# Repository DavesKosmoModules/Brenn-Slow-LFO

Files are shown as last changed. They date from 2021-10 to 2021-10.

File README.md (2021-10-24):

# Brenn-Slow-LFO

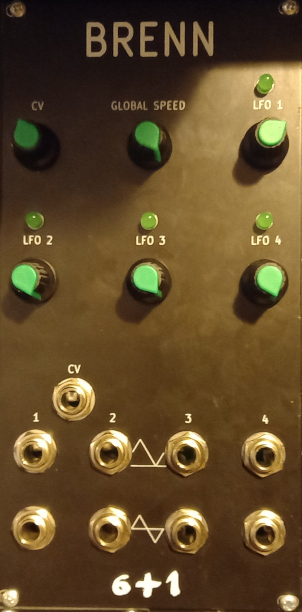
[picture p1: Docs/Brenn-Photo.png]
Brenn Photo


100mm Quad Slow LFO

- 4 Lfo's
- Each has a cycle duration between a few seconds and a few minutes, approx 6 sec 12 minutes
- Each LFO has it's own speed control
- A single global speed control
- CV control for the global speed (not 1V/Oct)
- Each LFO has both unipolar and bipolar outputs

I have been using the lfo for slow evolving movement of sounds, it is not a replacement for a standard lfo, normal tremolo
and vibrato can not be realized with this module.

It is based on the single cell VCO on the LM13700 datasheet, this is a triangle wave with a big step so I added
a LPF to each oscillator.

Contained are schematics & gerber files for pcb fabrication of both electrical aux and front panel. This is sutiable for entry level however a basic level of electronics, soldering, fault finding, and some basic tools are required.

[Schematic](/Docs/Brenn-Schematic.pdf)

[BOM](Docs/Brenn-BOM.pdf)

If you wish to edit in ki-cad the following dependencies are required

 https://github.com/holmesrichards/Kosmo_panel
 
 https://github.com/holmesrichards/aoKicad

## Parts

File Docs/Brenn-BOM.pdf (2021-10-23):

Id | Designator | Package | Quantity | Designation
| 1 RV3,RV4 | Potentiometer_Alpha_RD901F‐40‐00D_Single_Vertical_CircularHoles | | 2 100k

2

| C1,C2,C5,C6,C9,C10,C11,C12,C13,
| C14 | C_Disc_D6.0mm_W4.4mm_P5.00mm | | 10 0.1uF
| 3 C3,C4,C15,C16 | CP_Radial_D7.5mm_P2.50mm | | 4 470uF
| 4 C7,C8,C17,C18 | C_Disc_D6.0mm_W4.4mm_P5.00mm | | 4 1uF
| 5 C19,C20 | CP_Radial_D7.5mm_P2.50mm | | 2 10uF
| 6 D1,D2,D3,D4,D6,D7,D8,D9 | D_DO‐35_SOD27_P7.62mm_Horizontal | | 8 1N914
| 7 D5,D10,D11,D14 | LED_D5.0mm | | 4 LED
| 8 D12,D13 | D_DO‐41_SOD81_P12.70mm_Horizontal | | 2 1N5817
| 9 J1 | IDC‐Header_2x05_P2.54mm_Vertical | | 1 Power
| 10 J2 | PinSocket_1x12_P2.54mm_Vertical | | 1 TO JACKS
| 11 Q1,Q2,Q3,Q4 | TO‐92_Inline_Wide | | 4 2N3904

12

R1,R6,R7,R8,R14,R15,R16,R17,R18
,R19,R20,R21,R22,R27,R33,R34,R3
5,R39,R43,R44,R45,R46,R47,R48,R
49 | R_Axial_DIN0207_L6.3mm_D2.5mm_P10.16mm_Horizontal | 25 100k
13 R2,R3,R4,R5,R29,R30,R31,R32 | R_Axial_DIN0207_L6.3mm_D2.5mm_P10.16mm_Horizontal | 8 7.5k
14 R9,R10,R37,R38 | R_Axial_DIN0207_L6.3mm_D2.5mm_P10.16mm_Horizontal | 4 5.1k
15 R12,R13,R40,R41 | R_Axial_DIN0207_L6.3mm_D2.5mm_P10.16mm_Horizontal | 4 1M

16

R23,R24,R25,R26,R51,R52,R53,R5
4 | R_Axial_DIN0207_L6.3mm_D2.5mm_P10.16mm_Horizontal | 8 1k
17 R28,R36,R42,R50 | R_Axial_DIN0207_L6.3mm_D2.5mm_P10.16mm_Horizontal | 4 10k
18 RV1,RV2,RV6,RV7 | Potentiometer_Alpha_RD901F‐40‐00D_Single_Vertical_CircularHoles | 4 1M
19 RV8 | Potentiometer_Bourns_3299W_Vertical | 1 100k
20 U1,U2 | DIP‐16_W7.62mm_LongPads | 2 LM13700
21 U3,U4,U5 | DIP‐14_W7.62mm_LongPads | 3 TL074

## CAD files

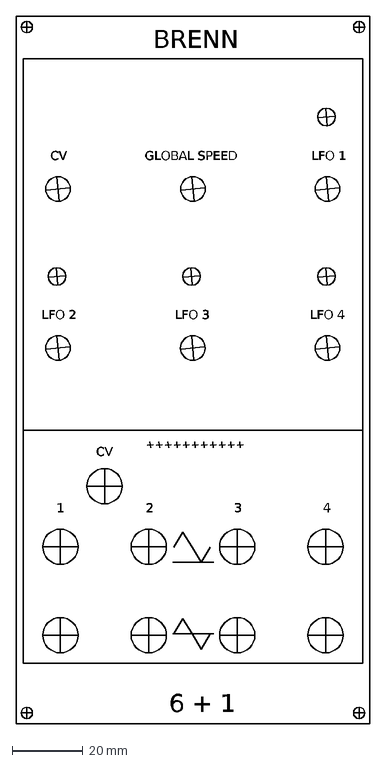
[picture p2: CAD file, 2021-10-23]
dwg/Frontv2.dxf
BRENN
CV
GLOBAL SPEED
LFO 1
LFO 2
LFO 3
LFO 4
1
2
3
4
6 + 1

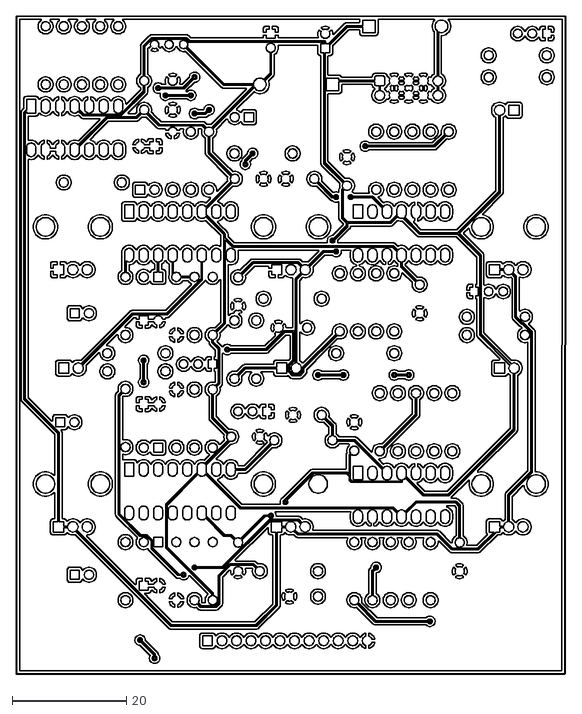
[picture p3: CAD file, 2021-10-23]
dwg/KOSMOS LFO6-F_Cu.dxf
96.1 x 115.1

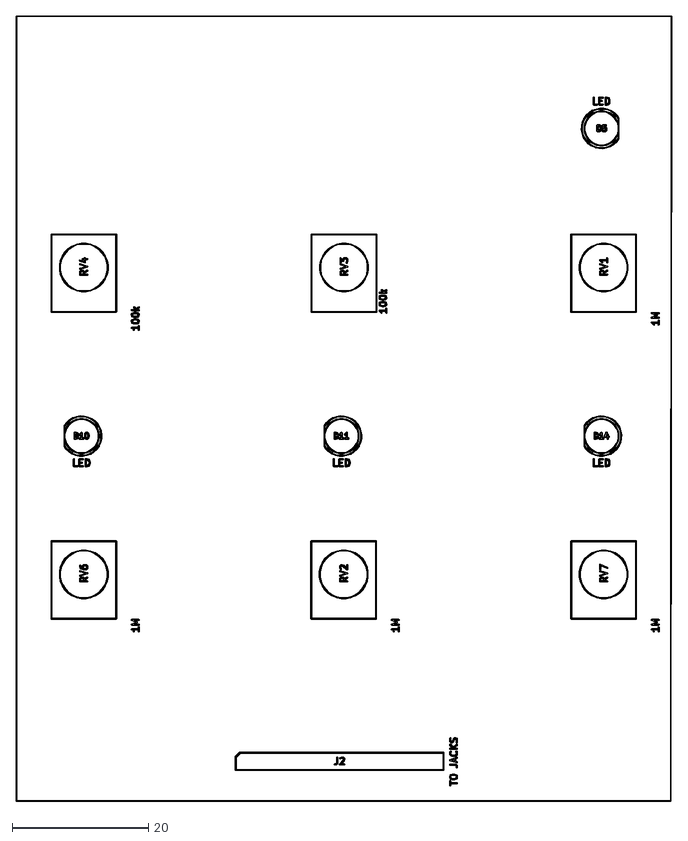
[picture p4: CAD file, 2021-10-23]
dwg/KOSMOS LFO6-F_Fab.dxf
96.1 x 115.1

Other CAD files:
dwg/KOSMOS LFO6-F_SilkS.dwg
dwg/LFOFrontPanel.dxf
dwg/KOSMOS LFO6-F_Cu.dwg
dwg/KOSMOS LFO6-F_Fab.dwg
dwg/KOSMOS LFO6-F_SilkS.dxf
dwg/LFOFrontPanel.dwg

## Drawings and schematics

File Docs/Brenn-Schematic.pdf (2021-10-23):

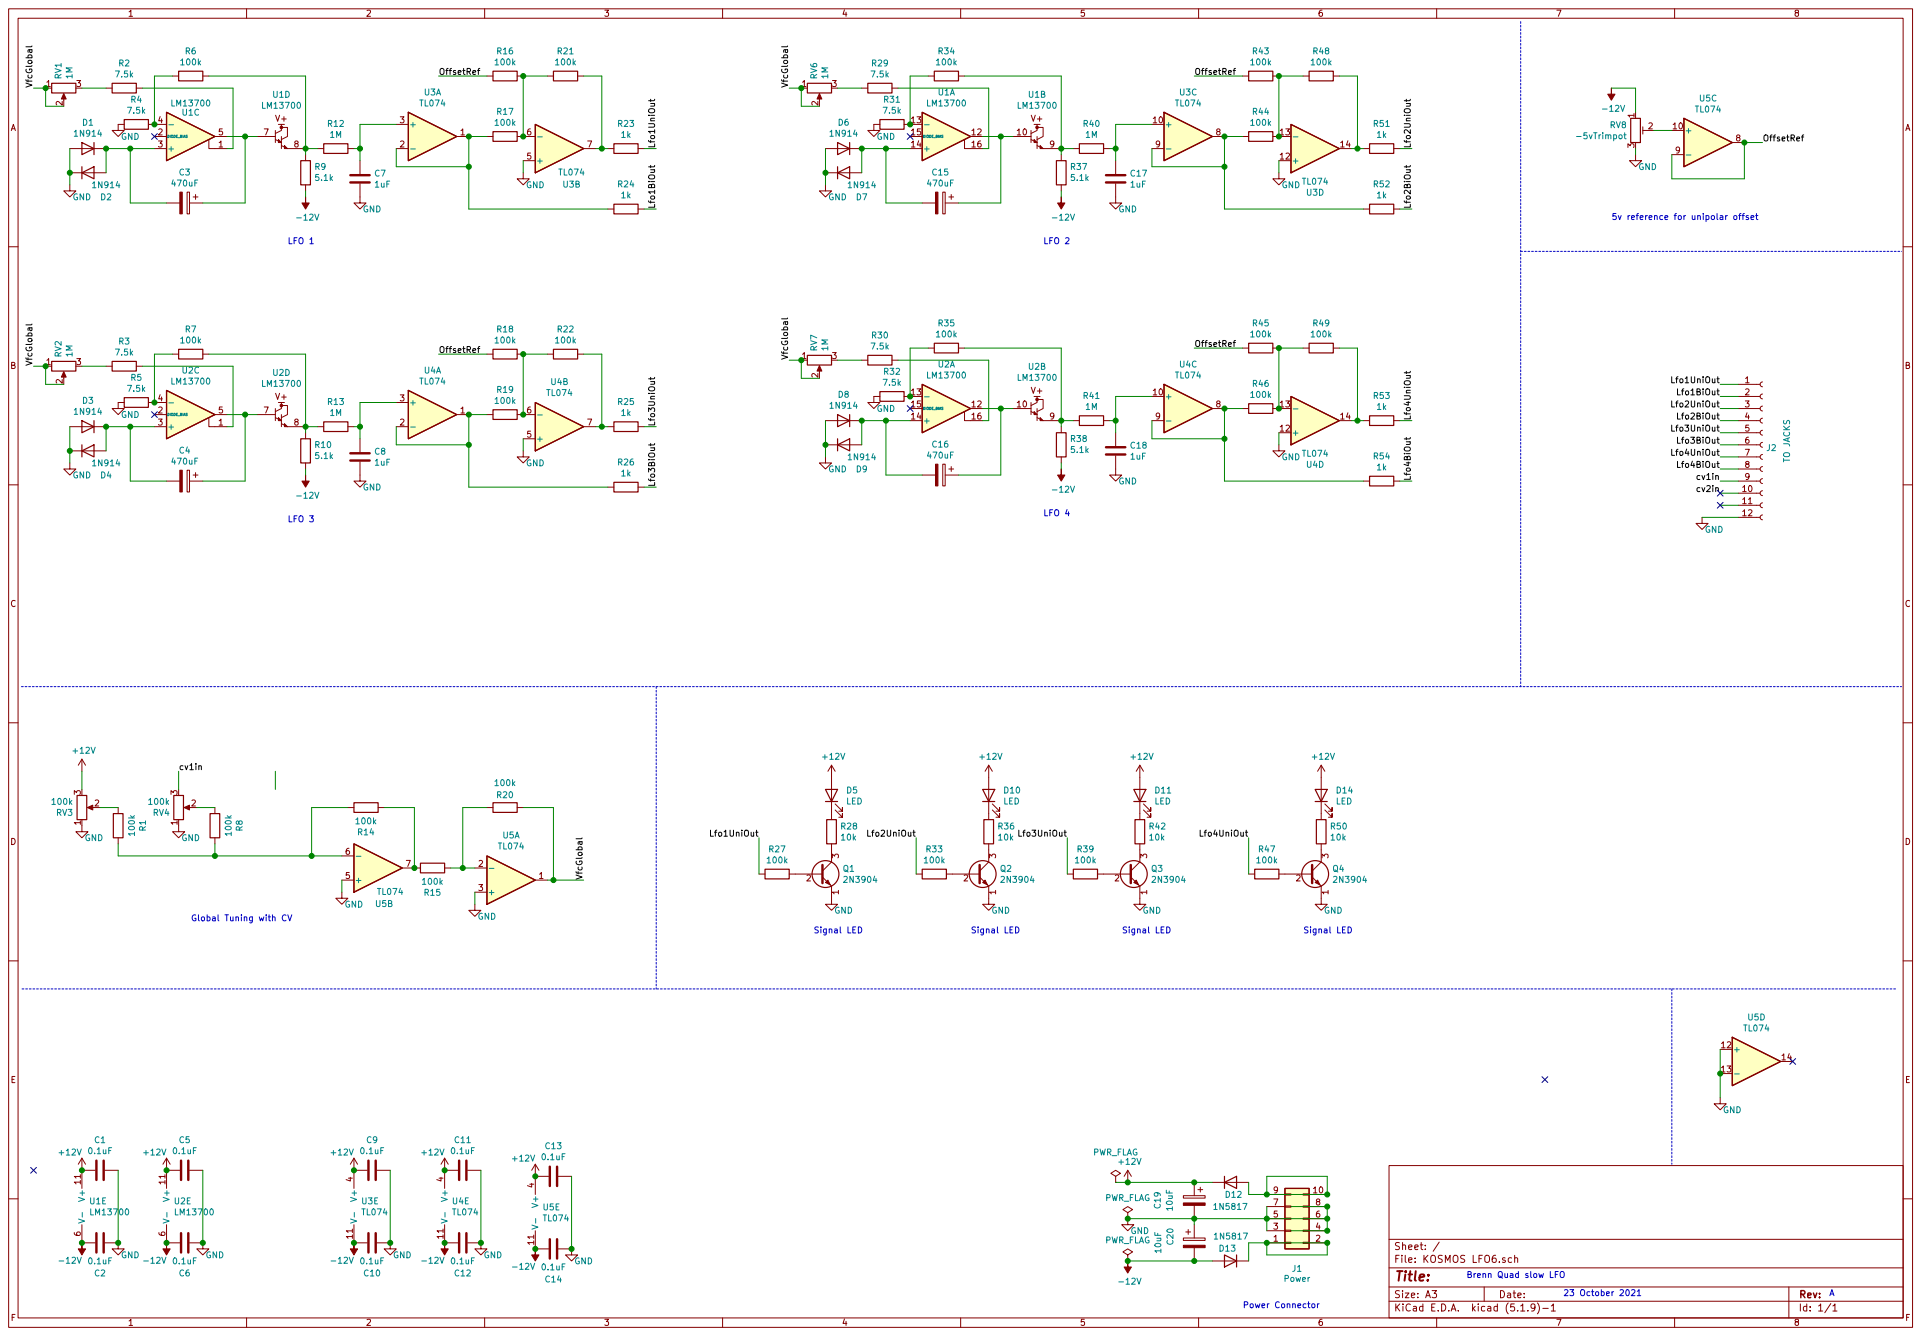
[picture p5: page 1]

5v reference for unipolar offset LFO 4

Global Tuning with CV

Brenn Quad slow LFO

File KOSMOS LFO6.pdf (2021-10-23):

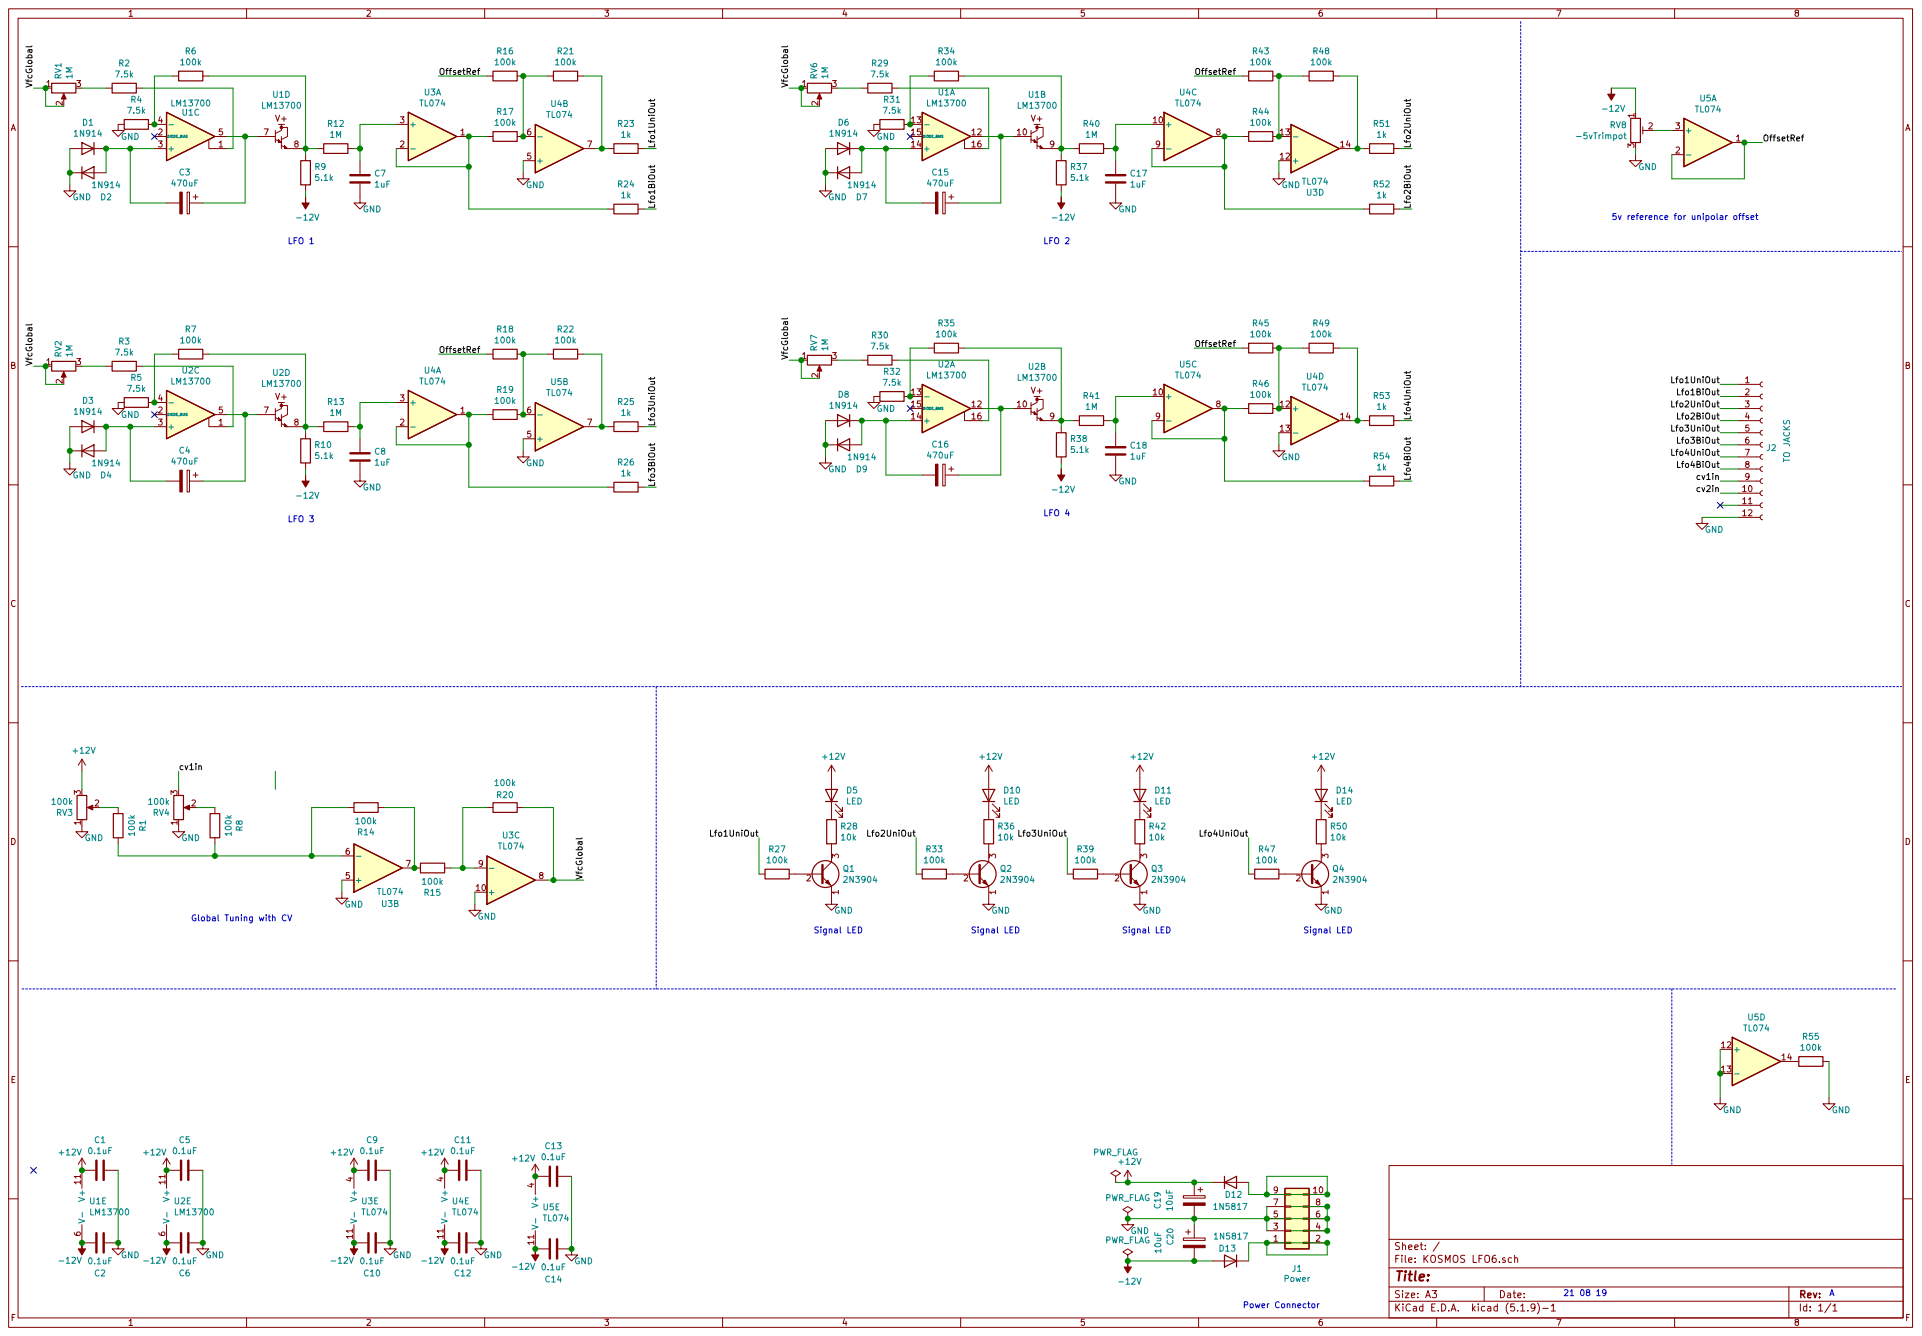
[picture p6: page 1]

5v reference for unipolar offset

Global Tuning with CV

Id: 1/1 Title: File: KOSMOS LFO6.sch Sheet: /

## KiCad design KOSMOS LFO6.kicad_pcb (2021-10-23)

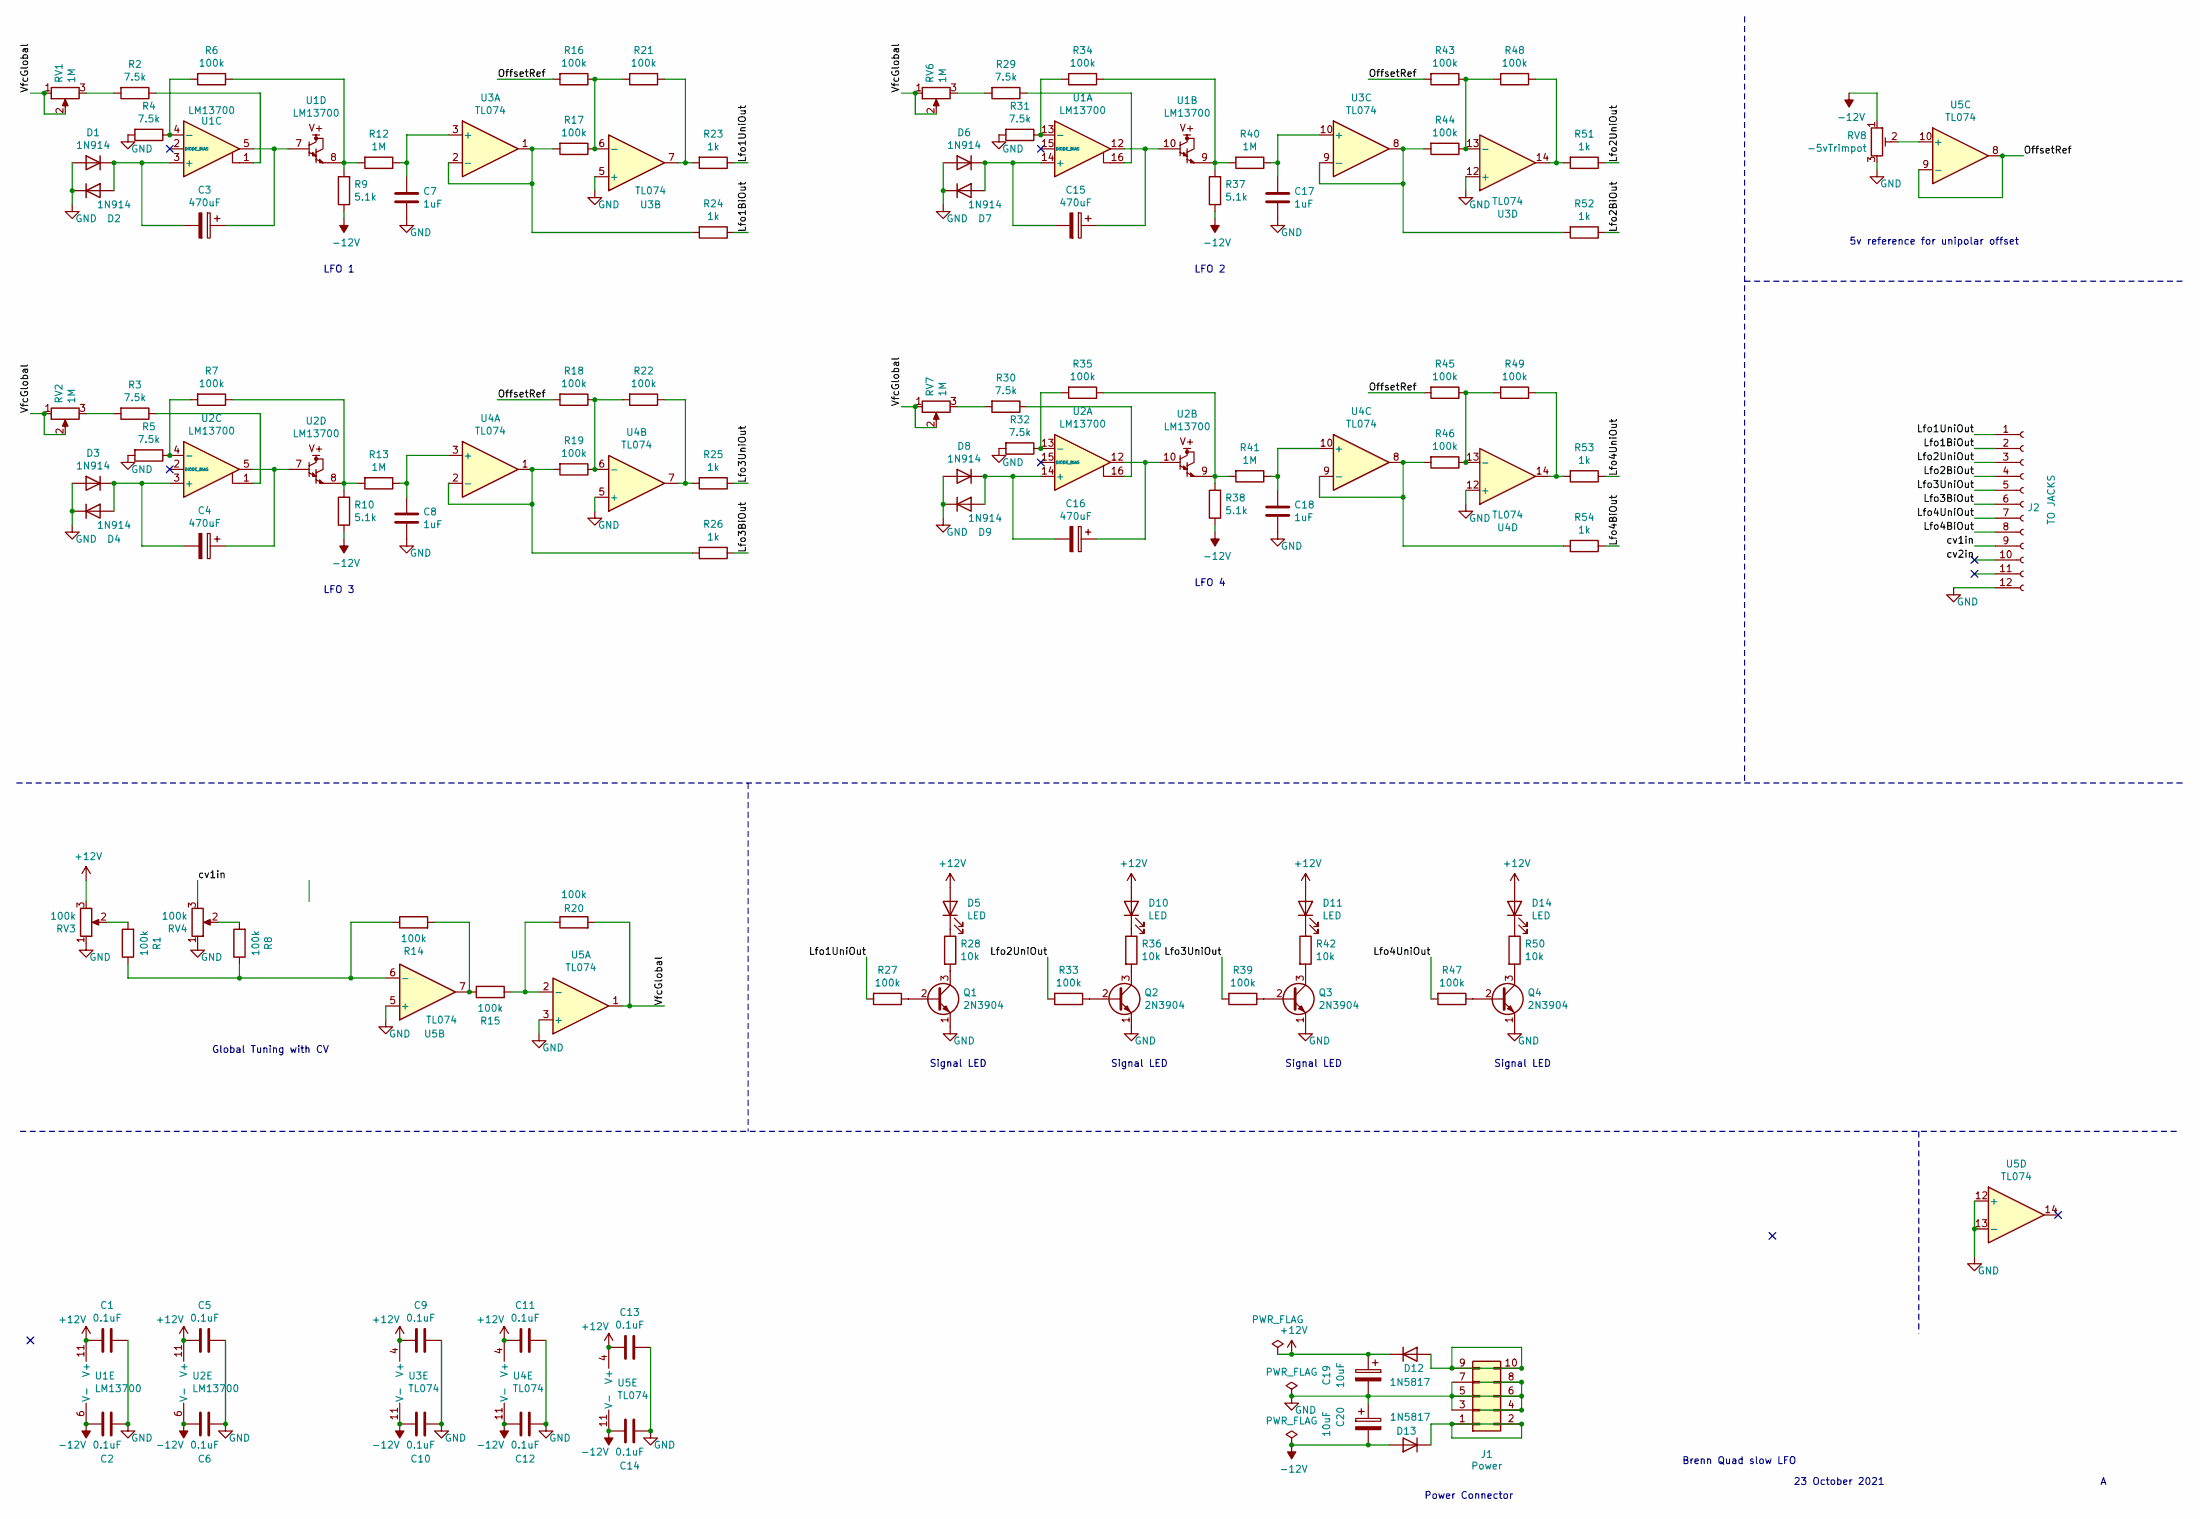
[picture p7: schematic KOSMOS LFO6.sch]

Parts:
C1, C2, C5, C6, C9, C10, C11, C12, C13, C14: 0.1uF; C_Disc_D6.0mm_W4.4mm_P5.00mm
C3, C4, C15, C16: 470uF; CP_Radial_D7.5mm_P2.50mm
C7, C8, C17, C18: 1uF; C_Disc_D6.0mm_W4.4mm_P5.00mm
C19, C20: 10uF; CP_Radial_D7.5mm_P2.50mm
D1, D2, D3, D4, D6, D7, D8, D9: 1N914; D_DO-35_SOD27_P7.62mm_Horizontal
D5, D10, D11, D14: LED; LED_D5.0mm
D12, D13: 1N5817; D_DO-41_SOD81_P12.70mm_Horizontal
J1: Power; IDC-Header_2x05_P2.54mm_Vertical
J2: TO JACKS; PinSocket_1x12_P2.54mm_Vertical
Q1, Q2, Q3, Q4: 2N3904; TO-92_Inline_Wide
R1, R6, R7, R8, R14, R15, R16, R17, R18, R19, R20, R21, R22, R27, R33, R34, R35, R39, R43, R44, R45, R46, R47, R48, R49: 100k; R_Axial_DIN0207_L6.3mm_D2.5mm_P10.16mm_Horizontal
R2, R3, R4, R5, R29, R30, R31, R32: 7.5k; R_Axial_DIN0207_L6.3mm_D2.5mm_P10.16mm_Horizontal
R9, R10, R37, R38: 5.1k; R_Axial_DIN0207_L6.3mm_D2.5mm_P10.16mm_Horizontal
R12, R13, R40, R41: 1M; R_Axial_DIN0207_L6.3mm_D2.5mm_P10.16mm_Horizontal
R23, R24, R25, R26, R51, R52, R53, R54: 1k; R_Axial_DIN0207_L6.3mm_D2.5mm_P10.16mm_Horizontal
R28, R36, R42, R50: 10k; R_Axial_DIN0207_L6.3mm_D2.5mm_P10.16mm_Horizontal
RV1, RV2, RV6, RV7: 1M; Potentiometer_Alpha_RD901F-40-00D_Single_Vertical_CircularH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
RV3, RV4: 100k; Potentiometer_Alpha_RD901F-40-00D_Single_Vertical_CircularH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
RV8: -5vTrimpot; Potentiometer_Bourns_3299W_Vertical
U1, U2: LM13700; DIP-16_W7.62mm_LongPads
U3, U4, U5: TL074; DIP-14_W7.62mm_LongPads

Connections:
+12V: C1.2, C5.2, C9.2, C11.2, C13.2, C19.1, D5.2 (A), D10.2 (A), D11.2 (A), D12.1 (K), D14.2 (A), RV3.3, U1.11 (V+), U2.11 (V+), U3.4 (V+), U4.4 (V+), U5.4 (V+)
-12V: C2.2, C6.2, C10.2, C12.2, C14.2, C20.2, D13.2 (A), R9.1, R10.1, R37.1, R38.1, RV8.1, U1.6 (V-), U2.6 (V-), U3.11 (V-), U4.11 (V-), U5.11 (V-)
/Lfo1BiOut: J2.2, R24.1
/Lfo1UniOut: J2.1, R23.1, R27.2
/Lfo2BiOut: J2.4, R52.1
/Lfo2UniOut: J2.3, R33.2, R51.1
/Lfo3BiOut: J2.6, R26.1
/Lfo3UniOut: J2.5, R25.1, R39.2
/Lfo4BiOut: J2.8, R54.1
/Lfo4UniOut: J2.7, R47.2, R53.1
/OffsetRef: R16.2, R18.2, R43.2, R45.2, U5.8, U5.9 (-)
/VfcGlobal: R20.2, RV1.1, RV1.2, RV2.1, RV2.2, RV6.1, RV6.2, RV7.1, RV7.2, U5.1
/cv1in: J2.9, RV4.3
/cv2in: J2.10
GND: C1.1, C2.1, C5.1, C6.1, C7.2, C8.2, C9.1, C10.1, C11.1, C12.1, C13.1, C14.1, C17.2, C18.2, C19.2, C20.1, D1.2 (A), D2.1 (K), D3.2 (A), D4.1 (K), D6.2 (A), D7.1 (K), D8.2 (A), D9.1 (K), J1.3, J1.4, J1.5, J1.6, J1.7, J1.8, J2.12, Q1.1 (E), Q2.1 (E), Q3.1 (E), Q4.1 (E), R4.2, R5.2, R31.2, R32.2, RV3.1, RV4.1, RV8.3, U3.5 (+), U3.12 (+), U4.5 (+), U4.12 (+), U5.3 (+), U5.5 (+), U5.12 (+), U5.13 (-)
unnamed: C3.1, U1.5, U1.7
unnamed: C3.2, D1.1 (K), D2.2 (A), U1.3 (+)
unnamed: C4.1, U2.5, U2.7
unnamed: C4.2, D3.1 (K), D4.2 (A), U2.3 (+)
unnamed: C7.1, R12.1, U3.3 (+)
unnamed: C8.1, R13.1, U4.3 (+)
unnamed: C15.1, U1.10, U1.12
unnamed: C15.2, D6.1 (K), D7.2 (A), U1.14 (+)
unnamed: C16.1, U2.10, U2.12
unnamed: C16.2, D8.1 (K), D9.2 (A), U2.14 (+)
unnamed: C17.1, R40.1, U3.10 (+)
unnamed: C18.1, R41.1, U4.10 (+)
unnamed: D5.1 (K), R28.1
unnamed: D10.1 (K), R36.1
unnamed: D11.1 (K), R42.1
unnamed: D12.2 (A), J1.9, J1.10
unnamed: D13.1 (K), J1.1, J1.2
unnamed: D14.1 (K), R50.1
unnamed: Q1.2 (B), R27.1
unnamed: Q1.3 (C), R28.2
unnamed: Q2.2 (B), R33.1
unnamed: Q2.3 (C), R36.2
unnamed: Q3.2 (B), R39.1
unnamed: Q3.3 (C), R42.2
unnamed: Q4.2 (B), R47.1
unnamed: Q4.3 (C), R50.2
unnamed: R1.1, R8.1, R14.1, U5.6 (-)
unnamed: R1.2, RV3.2
unnamed: R2.1, U1.1
unnamed: R2.2, RV1.3
unnamed: R3.1, U2.1
unnamed: R3.2, RV2.3
unnamed: R4.1, R6.2, U1.4 (-)
unnamed: R5.1, R7.2, U2.4 (-)
unnamed: R8.2, RV4.2
unnamed: R7.1, R10.2, R13.2, U2.8
unnamed: R6.1, R9.2, R12.2, U1.8
unnamed: R14.2, R15.1, U5.7
unnamed: R15.2, R20.1, U5.2 (-)
unnamed: R16.1, R17.1, R21.2, U3.6 (-)
unnamed: R17.2, R24.2, U3.1, U3.2 (-)
unnamed: R18.1, R19.1, R22.2, U4.6 (-)
unnamed: R19.2, R26.2, U4.1, U4.2 (-)
unnamed: R21.1, R23.2, U3.7
unnamed: R22.1, R25.2, U4.7
unnamed: R29.1, U1.16
unnamed: R29.2, RV6.3
unnamed: R30.1, U2.16
unnamed: R30.2, RV7.3
unnamed: R31.1, R34.2, U1.13 (-)
unnamed: R32.1, R35.2, U2.13 (-)
unnamed: R34.1, R37.2, R40.2, U1.9
unnamed: R35.1, R38.2, R41.2, U2.9
unnamed: R43.1, R44.1, R48.2, U3.13 (-)
unnamed: R44.2, R52.2, U3.8, U3.9 (-)
unnamed: R45.1, R46.1, R49.2, U4.13 (-)
unnamed: R46.2, R54.2, U4.8, U4.9 (-)
unnamed: R48.1, R51.2, U3.14
unnamed: R49.1, R53.2, U4.14
unnamed: RV8.2, U5.10 (+)

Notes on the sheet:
Power Connector
Signal LED
LFO 1
LFO 2
LFO 3
LFO 4
Global Tuning with CV
5v reference for unipolar offset
23 October 2021
Brenn Quad slow LFO

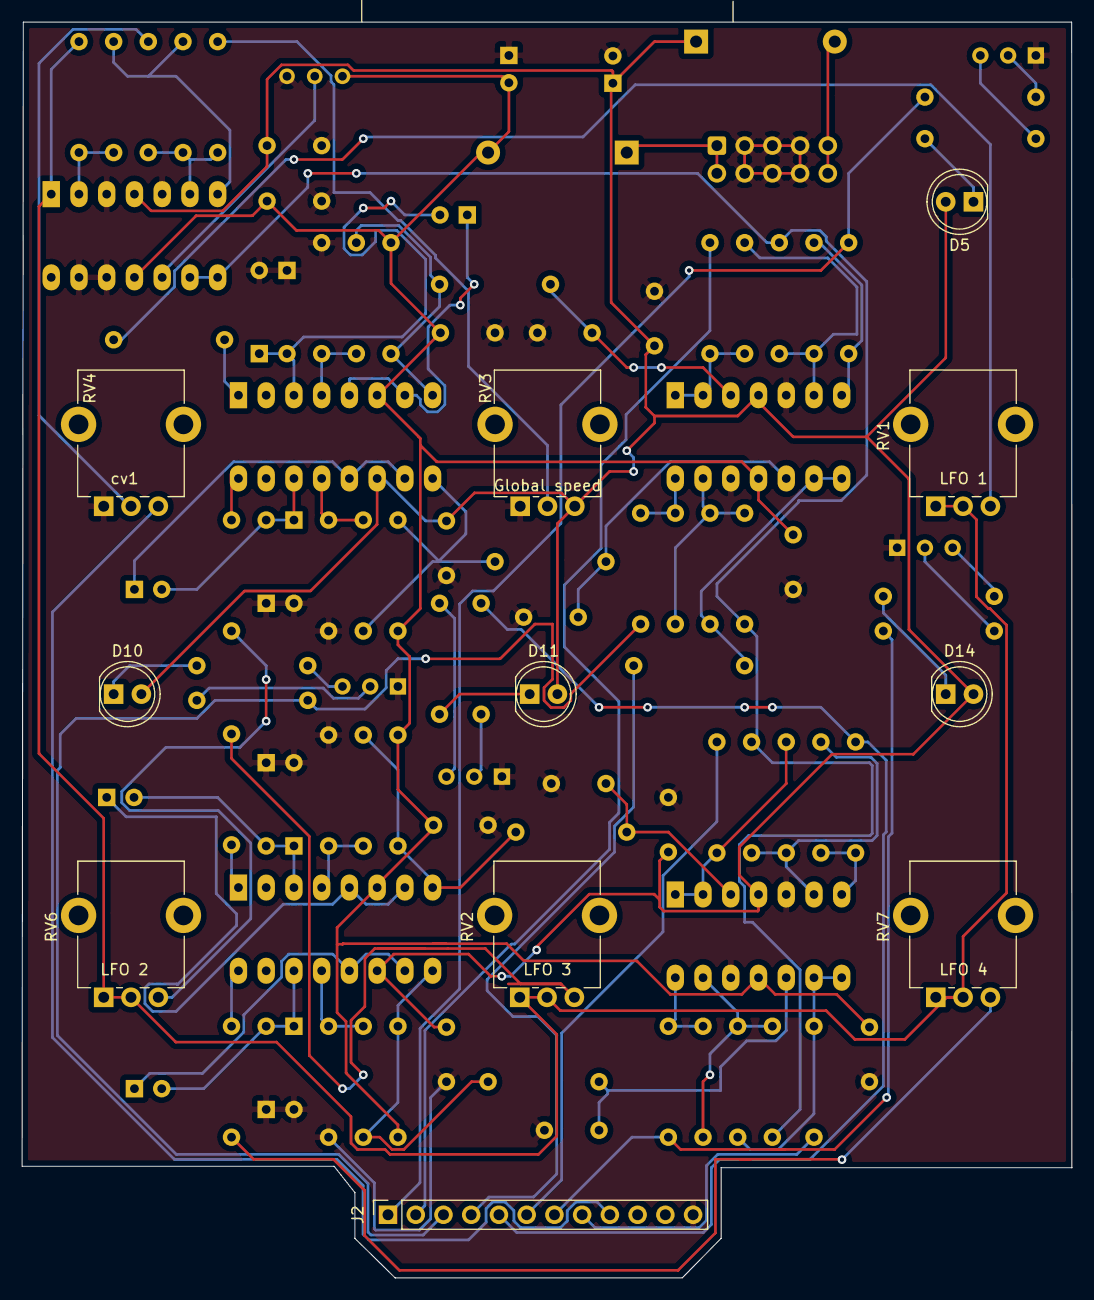
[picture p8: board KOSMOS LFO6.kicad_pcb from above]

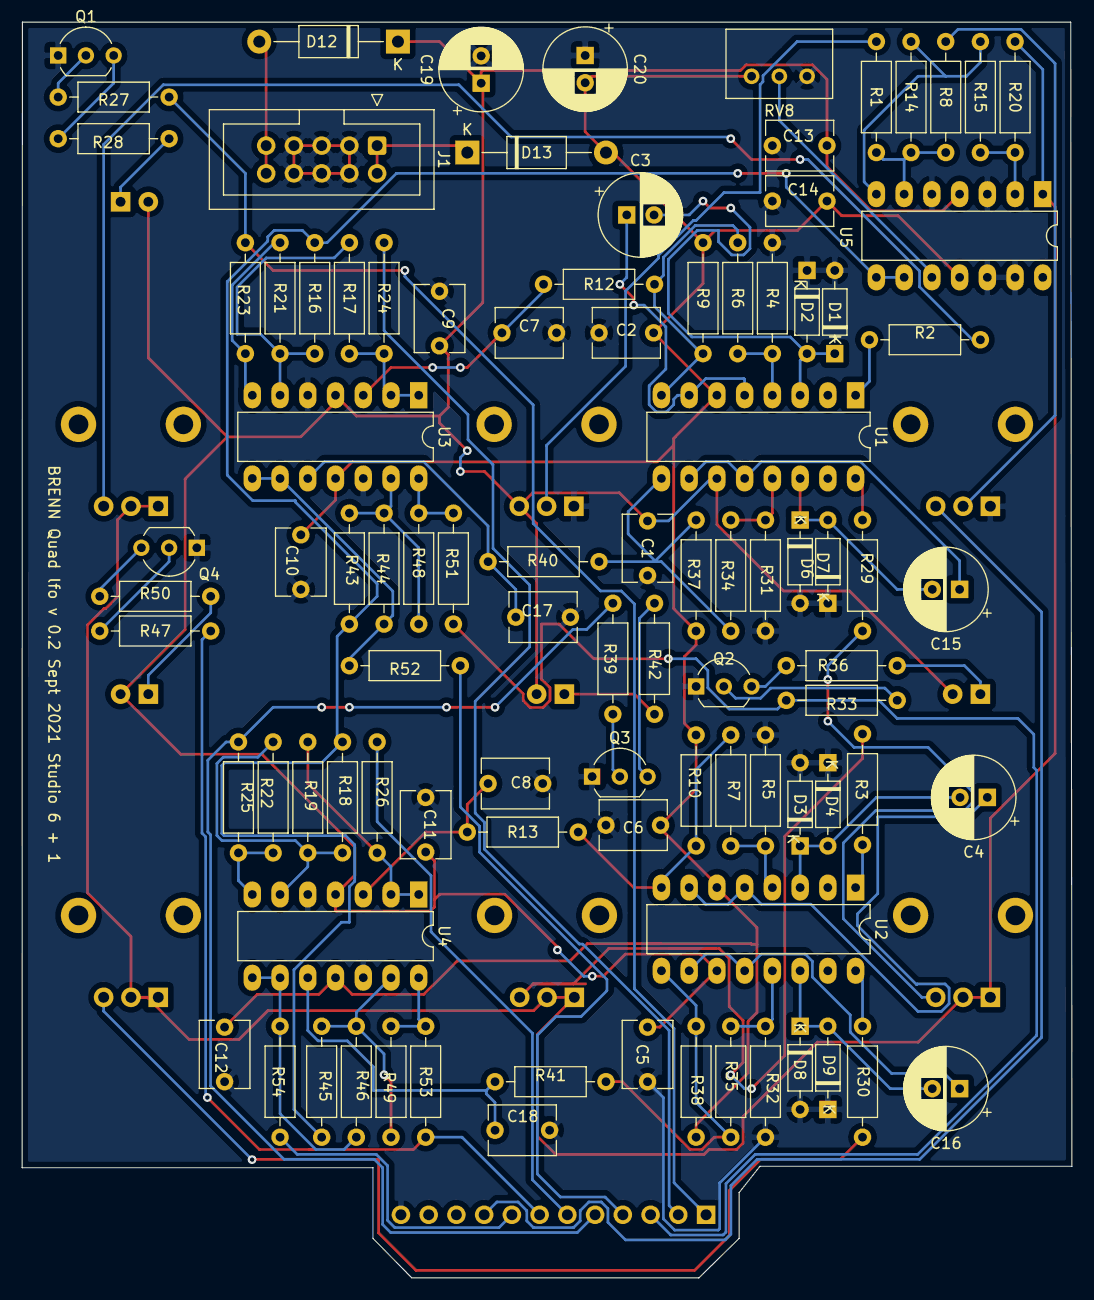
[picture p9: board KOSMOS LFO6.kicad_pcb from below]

Board: 2 copper layers, 96.1 x 115.0 mm, 105 parts (94 on the bottom side), 74 nets.

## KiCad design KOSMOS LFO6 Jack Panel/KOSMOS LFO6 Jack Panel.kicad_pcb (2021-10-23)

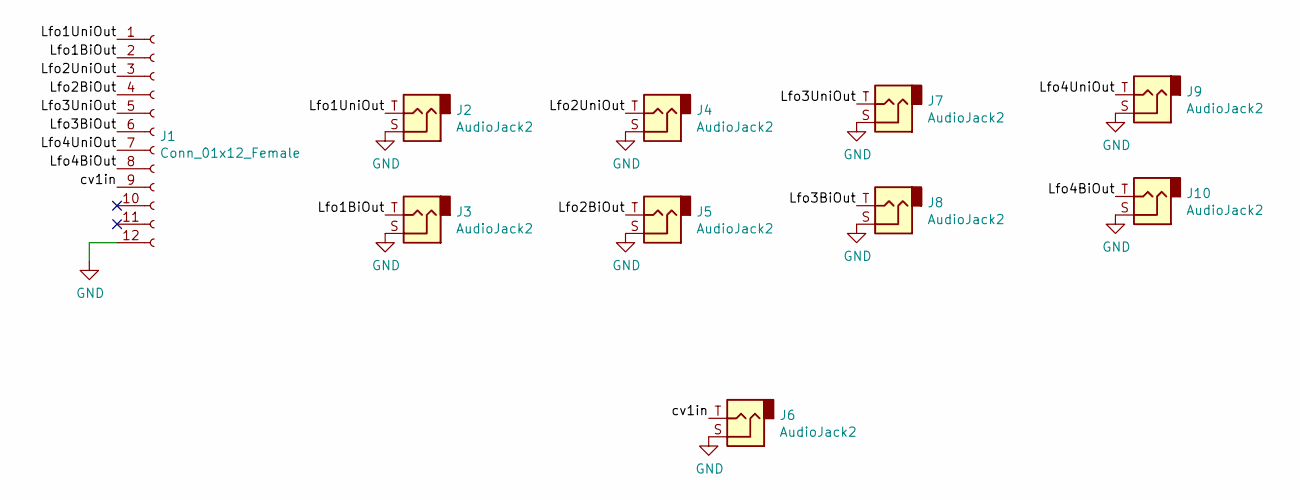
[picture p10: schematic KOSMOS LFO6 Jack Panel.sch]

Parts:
J1: Conn_01x12_Female; PinHeader_1x12_P2.54mm_Vertical
J2, J3, J4, J5, J6, J7, J8, J9, J10: AudioJack2; Jack_6.35mm_PJ_629HAN

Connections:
/Lfo1BiOut: J1.2, J3.T
/Lfo1UniOut: J1.1, J2.T
/Lfo2BiOut: J1.4, J5.T
/Lfo2UniOut: J1.3, J4.T
/Lfo3BiOut: J1.6, J8.T
/Lfo3UniOut: J1.5, J7.T
/Lfo4BiOut: J1.8, J10.T
/Lfo4UniOut: J1.7, J9.T
/cv1in: J1.9, J6.T
GND: J1.12, J2.S, J3.S, J4.S, J5.S, J6.S, J7.S, J8.S, J9.S, J10.S

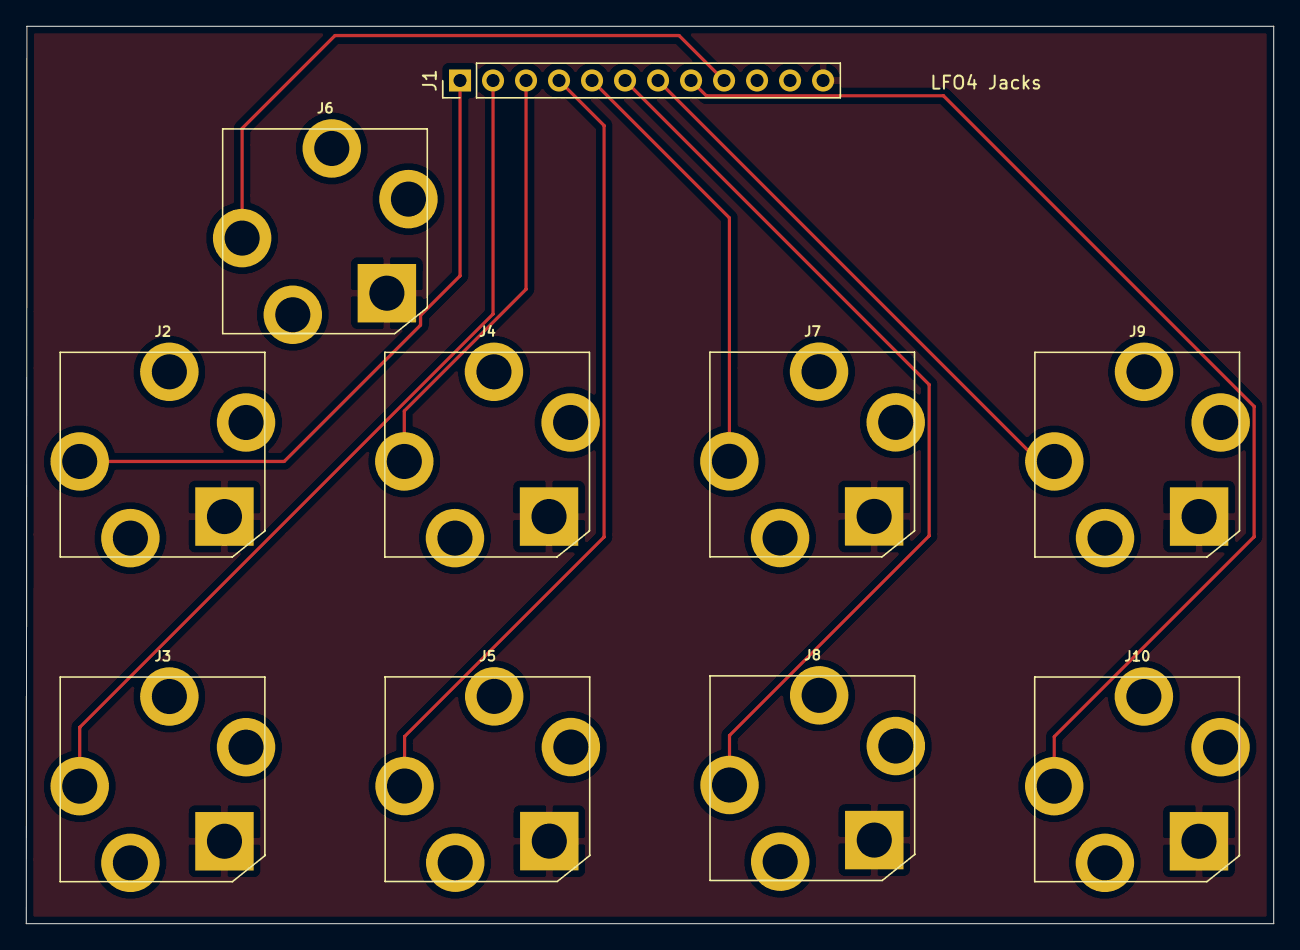
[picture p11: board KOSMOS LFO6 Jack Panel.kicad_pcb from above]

Board: 2 copper layers, 96.0 x 69.1 mm, 10 parts (0 on the bottom side), 10 nets.
